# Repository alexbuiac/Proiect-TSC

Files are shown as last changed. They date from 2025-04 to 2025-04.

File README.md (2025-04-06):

# Proiect TSC 2025

## 1. Diagrama bloc a device-ului

```mermaid
flowchart TB
  USB-C -->|5V| Charger["Charger MCP73831"]
  Charger -->LiPo["Battery"]
  LiPo --> LDO["3V3 LDO"]
  
  ESP32["ESP32-C6-WROOM-1"]
  
  LDO -->|3.3V| ESP32
  LDO -->|3.3V| Display
  LDO -->|3.3V| SDCard
  LDO -->|3.3V| RTC
  LDO -->|3.3V| BME688
  LDO -->|3.3V| BatteryGauge
  
  ESP32 -- SPI --> Display["7.5 E-Ink Display Waveshare WSH-13187"]
  ESP32 -- SPI --> SDCard["SD Card Connector"]
  ESP32 -- GPIO --> Buttons["Buttons (3x)"]
  ESP32 -- I2C --> BME688["Environment Sensor BME688"]
  ESP32 -- I2C --> BatteryGauge["Battery Percentage Gauge MAX17048"]
  ESP32 -- I2C --> RTC["Clock DS3231"]
  ESP32 -- USB --> USB-C
  
  LDO -->|3.3V| ESP32
  LDO -->|3.3V| Display
  LDO -->|3.3V| SDCard
  LDO -->|3.3V| RTC
  LDO -->|3.3V| BME688
  LDO -->|3.3V| BatteryGauge
```
## 2. BIll of Materials

| Name of component | Device | Check Prices | DataSheet |
|---|---|---|---|
| BOOT_BUTTON | BUTTON_CUSYOMV1 | https://industry.panasonic.com/global/en/products/control/switch/light-touch/number/evqpuj02k | https://industry.panasonic.com/global/en/products/control/switch/light-touch/number/evqpuj02k |
| C1 | ESP32_WROVER_EAGLE-LTSPICE_CC0402 | https://industry.panasonic.com/global/en/products/control/switch/light-touch/number/evqpuj02k | https://industry.panasonic.com/global/en/products/control/switch/light-touch/number/evqpuj02k |
| C1_BAT | ESP32_WROVER_EAGLE-LTSPICE_CC0402 | #N/A | #N/A |
| C1_BAT1 | EAGLE-LTSPICE_CC0402 | #N/A | #N/A |
| C1_BAT2 | EAGLE-LTSPICE_CC0402 | #N/A | #N/A |
| C2 | ESP32_WROVER_EAGLE-LTSPICE_CC0402 | #N/A | #N/A |
| C2_BAT\ | ESP32_WROVER_EAGLE-LTSPICE_CC0402 | #N/A | #N/A |
| C3 | RCL_CPOL-EUCT3528 | #N/A | #N/A |
| C4 | ESP32_WROVER_EAGLE-LTSPICE_CC0402 | #N/A | #N/A |
| C4_USB | ESP32_WROVER_EAGLE-LTSPICE_CC0402 | #N/A | #N/A |
| C5 | ESP32_WROVER_EAGLE-LTSPICE_CC0402 | #N/A | #N/A |
| C5_USB | ESP32_WROVER_EAGLE-LTSPICE_CC0402 | #N/A | #N/A |
| C6 | ESP32_WROVER_EAGLE-LTSPICE_CC0402 | #N/A | #N/A |
| C7 | ESP32_WROVER_EAGLE-LTSPICE_CC0402 | #N/A | #N/A |
| C8 | ESP32_WROVER_EAGLE-LTSPICE_CC0402 | #N/A | #N/A |
| C9 | EAGLE-LTSPICE_CC0402 | #N/A | #N/A |
| C10 | ESP32_WROVER_EAGLE-LTSPICE_CC0402 | #N/A | #N/A |
| C10_SUPERCAP | CPH3225A | https://www.snapeda.com/parts/CPH3225A/Seiko+Instruments/view-part/?ref=eda | https://www.snapeda.com/parts/CPH3225A/Seiko+Instruments/view-part/?ref=eda |
| CHANGE_BUTTON | BUTTON_CUSYOMV1 | https://industry.panasonic.com/global/en/products/control/switch-light-touch/number/evqpuj02k | https://industry.panasonic.com/global/en/products/control/switch-light-touch/number/evqpuj02k |
| CHG_LED | ADAFRUIT_LEDCHIP-LED0603 | https://www.snapeda.com/parts/KP-1608SURCK/Kingbright/view-part/?ref=search&t=LED%200603 | https://www.snapeda.com/parts/KP-1608SURCK/Kingbright/view-part/?ref=search&t=LED%200603 |
| C_DELAY | ESP32_WROVER_EAGLE-LTSPICE_CC0402 | #N/A | #N/A |
| D1 | USBLC6-2SC6Y | https://www.snapeda.com/parts/USBLC6-2SC6Y/STMicroelectronics/view-part/?ref=eda | https://www.snapeda.com/parts/USBLC6-2SC6Y/STMicroelectronics/view-part/?ref=eda |
| D2 | ESP32_WROVER_AVX---SD0805S020S1R0_AVX_... | https://eu.mouser.com/ProductDetail/KYOCERA-AVX/SD0805S020S1R0?qs=jCA%252BPfw4LHbpkAoSnwrdjw%3D%3D | http://datasheets.avx.com/schottky.pdf |
| D3 | MBR0530 | https://eu.mouser.com/ProductDetail/KYOCERA-AVX/SD0805S020S1R0?qs=jCA%252BPfw4LHbpkAoSnwrdjw%3D%3D | https://eu.mouser.com/ProductDetail/KYOCERA-AVX/SD0805S020S1R0?qs=jCA%252BPfw4LHbpkAoSnwrdjw%3D%3D |
| D4 | MBR0530 | https://www.snapeda.com/parts/MBR0530/Onsemi/view-part/?ref=eda | https://www.snapeda.com/parts/MBR0530/Onsemi/view-part/?ref=eda |
| D5 | MBR0530 | https://www.snapeda.com/parts/MBR0530/Onsemi/view-part/?ref=eda | https://www.snapeda.com/parts/MBR0530/Onsemi/view-part/?ref=eda |
| D6 | PGB1010603MR | https://www.snapeda.com/parts/PGB1010603MR/Littelfuse/view-part/?ref=eda | https://www.snapeda.com/parts/PGB1010603MR/Littelfuse/view-part/?ref=eda |
| D7 | ESP32_WROVER_AVX---SD0805S020S1R0_AVX_... | https://eu.mouser.com/ProductDetail/KYOCERA-AVX/SD0805S020S1R0?qs=jCA%252BPfw4LHbpkAoSnwrdjw%3D%3D | http://datasheets.avx.com/schottky.pdf |
| D8 | PGB1010603MR | https://www.snapeda.com/parts/PGB1010603MR/Littelfuse/view-part/?ref=eda | https://www.snapeda.com/parts/PGB1010603MR/Littelfuse/view-part/?ref=eda |
| D9 | PGB1010603MR | https://www.snapeda.com/parts/PGB1010603MR/Littelfuse/view-part/?ref=eda | https://www.snapeda.com/parts/PGB1010603MR/Littelfuse/view-part/?ref=eda |
| D10 | PGB1010603MR | https://www.snapeda.com/parts/PGB1010603MR/Littelfuse/view-part/?ref=eda | https://www.snapeda.com/parts/PGB1010603MR/Littelfuse/view-part/?ref=eda |
| D11 | PGB1010603MR | https://www.snapeda.com/parts/PGB1010603MR/Littelfuse/view-part/?ref=eda | https://www.snapeda.com/parts/PGB1010603MR/Littelfuse/view-part/?ref=eda |
| D12 | PGB1010603MR | https://www.snapeda.com/parts/PGB1010603MR/Littelfuse/view-part/?ref=eda | https://www.snapeda.com/parts/PGB1010603MR/Littelfuse/view-part/?ref=eda |
| EPD_C1 | ESP32_WROVER_EAGLE-LTSPICE_CC0402 | #N/A | #N/A |
| EPD_C2 | ESP32_WROVER_EAGLE-LTSPICE_CC0402 | #N/A | #N/A |
| EPD_C5 | ESP32_WROVER_EAGLE-LTSPICE_CC0402 | #N/A | #N/A |
| EPD_C6 | ESP32_WROVER_EAGLE-LTSPICE_CC0402 | #N/A | #N/A |
| EPD_C7 | ESP32_WROVER_EAGLE-LTSPICE_CC0402 | #N/A | #N/A |
| EPD_C8 | ESP32_WROVER_EAGLE-LTSPICE_CC0402 | #N/A | #N/A |
| EPD_C9 | ESP32_WROVER_EAGLE-LTSPICE_CC0402 | #N/A | #N/A |
| EPD_C10 | ESP32_WROVER_EAGLE-LTSPICE_CC0402 | #N/A | #N/A |
| EPD_C11 | ESP32_WROVER_EAGLE-LTSPICE_CC0402 | #N/A | #N/A |
| EPD_C12 | ESP32_WROVER_EAGLE-LTSPICE_CC0402 | #N/A | #N/A |
| IC1 | BD5229G-TR | https://componentsearchengine.com/part-view/BD5229G-TR/ROHM%20Semiconductor | https://componentsearchengine.com/part-view/BD5229G-TR/ROHM%20Semiconductor |
| IC4 | XC6220A331MR-G | https://componentsearchengine.com/part-view/XC6220A331MR-G/Torex | https://componentsearchengine.com/part-view/XC6220A331MR-G/Torex |
| J1 | FH34SRJ-24S-0.5SH_99_ | https://componentsearchengine.com/part-view/XC6220A331MR-G/Torex | https://componentsearchengine.com/part-view/XC6220A331MR-G/Torex |
| J2 | SAMACSYS_PARTS_USB4110-GF-A | https://componentsearchengine.com/part-view/USB4110-GF-A/GCT%20(GLOBAL%20CONNECTOR%20TECHNOLOGY | https://componentsearchengine.com/part-view/USB4110-GF-A/GCT%20(GLOBAL%20CONNECTOR%20TECHNOLOGY |
| J3 | QWIIC_CONNECTORJS-1MM | #N/A | #N/A |
| J4 | 112A-TAAR-R03_ATTEND | https://store.comet.srl.ro/Catalogue/Product/43497/ | https://store.comet.srl.ro/Catalogue/Product/43497/ |
| L1 | 744043680IND_4828-WE-TPC_WRE | https://eu.mouser.com/ProductDetail/Wurth-Elektronik/744043680?qs=PGXP4M47uW6VkZq%252BkzjrHA%3D%3D | https://eu.mouser.com/ProductDetail/Wurth-Elektronik/744043680?qs=PGXP4M47uW6VkZq%252BkzjrHA%3D%3D |
| PFMF.050.1 | ESP32C6_VARISTORCN1812 | https://www.mouser.co.uk/ProductDetail/EPCOS-TDK/B72520T0350K062?qs=dEfas%2FXlABIszF52uu7vrg%3D%3D | https://www.mouser.co.uk/ProductDetail/EPCOS-TDK/B72520T0350K062?qs=dEfas%2FXlABIszF52uu7vrg%3D%3D |
| Q1 | ESP32_WROVER_SPARKFUN-DISCRETESEMI_MOSFET_...| https://componentsearchengine.com/part-view/DMG2305UX-7/Diodes%20Incorporated | https://componentsearchengine.com/part-view/DMG2305UX-7/Diodes%20Incorporated |
| Q2 | ESP32_WROVER_SPARKFUN-DISCRETESEMI_MOSFET_...| #N/A | #N/A |
| Q3 | D8 | https://componentsearchengine.com/part-view/SI1308EDL-T1-GE3/Vishay | https://componentsearchengine.com/part-view/SI1308EDL-T1-GE3/Vishay |
| R1 | ESP32_WROVER_EAGLE-LTSPICE_RR0402 | #N/A | #N/A |
| R1-PINH | ESP32_WROVER_EAGLE-LTSPICE_RR0402 | #N/A | #N/A |
| R1-PINH1 | ESP32_WROVER_EAGLE-LTSPICE_RR0402 | #N/A | #N/A |
| R1_BAT | ESP32_WROVER_EAGLE-LTSPICE_RR0402 | #N/A | #N/A |
| R1_PWRUSB | ESP32_WROVER_EAGLE-LTSPICE_RR0402 | #N/A | #N/A |
| R2 | ESP32_WROVER_EAGLE-LTSPICE_RR0402 | https://componentsearchengine.com/part-view/R0402%201%25%20100%20K%20(RC0402FR-07100KL | https://componentsearchengine.com/part-view/R0402%201%25%20100%20K%20(RC0402FR-07100KL |
| R2-PINH | ESP32_WROVER_EAGLE-LTSPICE_RR0402 | #N/A | #N/A |
| R2-PINH1 | ESP32_WROVER_EAGLE-LTSPICE_RR0402 | #N/A | #N/A |
| R2-USB | ESP32_WROVER_EAGLE-LTSPICE_RR0402 | #N/A | #N/A |
| R2-USB1 | ESP32_WROVER_EAGLE-LTSPICE_RR0402 | #N/A | #N/A |
| R2_BAT | ESP32_WROVER_EAGLE-LTSPICE_RR0402 | #N/A | #N/A |
| R3 | ESP32_WROVER_EAGLE-LTSPICE_RR0402 | #N/A | #N/A |
| R4 | ESP32_WROVER_EAGLE-LTSPICE_RR0402 | #N/A | #N/A |
| R5 | ESP32_WROVER_EAGLE-LTSPICE_RR0402 | #N/A | #N/A |
| R6 | ESP32_WROVER_EAGLE-LTSPICE_RR0402 | #N/A | #N/A |
| R7 | ESP32_WROVER_EAGLE-LTSPICE_RR0402 | #N/A | #N/A |
| R8 | ESP32_WROVER_EAGLE-LTSPICE_RR0402 | #N/A | #N/A |
| R9 | ESP32_WROVER_EAGLE-LTSPICE_RR0402 | #N/A | #N/A |
| R10 | ESP32_WROVER_EAGLE-LTSPICE_RR0402 | #N/A | #N/A |
| RESET_BUTTON | BUTTON_CUSYOMV1 | https://industry.panasonic.com/global/en/products/control/switch/light-touch/number/evqpuj02k | https://industry.panasonic.com/global/en/products/control/switch/light-touch/number/evqpuj02k |
| R_BOOT | ESP32_WROVER_EAGLE-LTSPICE_RR0402 | #N/A | #N/A |
| R_CAPACITOR | ESP32_WROVER_EAGLE-LTSPICE_RR0402 | #N/A | #N/A |
| R_CHANGE | ESP32_WROVER_EAGLE-LTSPICE_RR0402 | #N/A | #N/A |
| R_CL1 | ESP32_WROVER_EAGLE-LTSPICE_RR0402 | #N/A | #N/A |
| R_RESET | ESP32_WROVER_EAGLE-LTSPICE_RR0402 | #N/A | #N/A |
| SENSOR2 | ESP32_WROVER_BME680_BME680 | https://www.snapeda.com/parts/BME680/Bosch/view-part/?welcome=home | https://www.snapeda.com/parts/BME680/Bosch/view-part/?welcome=home |
| SJ1 | SJ | https://grabcad.com/library/solder-jumpers-1 | https://grabcad.com/library/solder-jumpers-1 |
| TP1 | TPTP20R | #N/A | #N/A |
| TP2 | TPTP20R | #N/A | #N/A |
| TP3 | TPTP20R | #N/A | #N/A |
| TP4 | TPTP20R | #N/A | #N/A |
| TP5 | TPTP20R | #N/A | #N/A |
| TP6 | TPTP20R | #N/A | #N/A |
| TP7 | TPTP20R | #N/A | #N/A |
| TP8 | TPTP20R | #N/A | #N/A |
| TP9 | TPTP20R | #N/A | #N/A |
| TP10 | TPTP20R | #N/A | #N/A |
| TP11 | TPTP20R | #N/A | #N/A |
| TP12 | TPTP20R | #N/A | #N/A |
| TP13 | TPTP20R | #N/A | #N/A |
| TP14 | TPTP20R | #N/A | #N/A |
| TP15 | TPTP20R | #N/A | #N/A |
| TP16 | TPTP20R | #N/A | #N/A |
| TP17 | TPTP20R | #N/A | #N/A |
| U1 | W25Q512JVEIQ | https://www.snapeda.com/parts/W25Q512JVEIQ/Winbond+Electronics/view-part/?ref=eda | https://www.snapeda.com/parts/W25Q512JVEIQ/Winbond+Electronics/view-part/?ref=eda |
| U2 | ESP32-C6-WROOM-1-N8 | https://www.snapeda.com/parts/ESP32-C6-WROOM-1-N8/Espressif+Systems/view-part/?ref=eda | https://www.snapeda.com/parts/ESP32-C6-WROOM-1-N8/Espressif+Systems/view-part/?ref=eda |
| U3 | DS3231SN# | https://www.snapeda.com/parts/DS3231SN%23/Analog+Devices/view-part/?ref=eda | https://www.snapeda.com/parts/DS3231SN%23/Analog+Devices/view-part/?ref=eda |
| U4 | MAX17048G+T10 | https://www.snapeda.com/parts/MAX17048G+T10/Analog+Devices/view-part/?ref=eda | https://www.snapeda.com/parts/MAX17048G+T10/Analog+Devices/view-part/?ref=eda |
| U5 | ESP32_WROVER_SPARKFUN-IC-POWER_MCP73831 | https://eu.mouser.com/ProductDetail/Microchip-Technology/MCP73831T-2ACI-OT?qs=yUQqVecv4qvbBQBGbHx0Mw%3D%3Dcf | https://eu.mouser.com/ProductDetail/Microchip-Technology/MCP73831T-2ACI-OT?qs=yUQqVecv4qvbBQBGbHx0Mw%3D%3Dcf |

## 3. Descrierea in detaliu a functionalitatilor hardware 

### 1. Microcontroller – ESP32-C6

- **Procesor**: 32-bit RISC-V, cu frecvență de până la 160MHz.
    
- **Memorie**: 512KB SRAM intern și 8MB flash extern (W25Q512JVEIQ).
    
- **Conectivitate**: Wi-Fi 6 (802.11ax), Bluetooth 5 (LE), USB 2.0 (full-speed).
    
- **Periferice**: SPI, I²C, UART, GPIO multiple.
    
- **Consum**: Posibilitate de moduri low-power (sleep, deep sleep).

### 2. Senzor de Mediu – BME688

- **Parametri măsurați**: Temperatură, Umiditate, Presiune și Calitate aer (VOC/eCO2).
    
- **Interfață**: I²C la 400kHz (SDA și SCL).
    
- **Consum**: Foarte mic (în jur de 2.1µA în standby și până la câteva mA în mod de măsurare).

### 3. Afișajul E-Paper (7.5 inch)

- **Model**: Waveshare (sau echivalent) cu rezoluție 800×480.
    
- **Interfață**: 4-wire SPI + semnale de control (CS, DC, RST, BUSY).
    
- **Consum**: Foarte redus în mod static (după refresh), dar necesită un curent mai mare în timpul refresh-ului (aprox. 15–25mA, în funcție de modul de actualizare).

### 4. Baterie și Managementul Energiei

- **Baterie Li-Po 2500mAh** (3.7V nominal).
    
- **IC de Încărcare**: MCP73831 (Microchip) – încărcare Li-Po prin USB-C (până la 1A).
    
- **Fuel Gauge**: MAX17048 – monitorizează nivelul de încărcare, tensiunea și starea bateriei (I²C).
    
- **LDO**: XC6220A331MR-G (exemplu) sau echivalent, pentru a asigura 3.3V stabil pentru microcontroller și restul componentelor.

### 5. USB-C Port

- **Rol**: Încărcare baterie + Transfer de date (USB 2.0 full-speed).
    
- **Protecții**: ESD (USBLC6-2SC6Y) + rezistențe de terminare.
    
- **Posibilitate**: Actualizări firmware prin USB (bootloader + tool extern) sau direct OTA prin Wi-Fi.

### 6. Butoane (3x Tactile Switch)

- **Tip**: Tactile switch Panasonic (sau echivalent).
    
- **Funcții**: Navigare meniu, selectare opțiune, întoarcere pagină etc.
    
- **Conexiune**: Fiecare buton se leagă la un GPIO al ESP32-C6 printr-un circuit de debouncing (rezistență și condensator) sau se poate face debouncing în firmware.

### 7. Conector Qwiic (I²C)

- Conector standard cu 4 pini: VCC, GND, SDA, SCL.
    
- Permite atașarea rapidă a altor senzori sau module I²C (expansiune, testare, prototipare rapidă).

### 8. SD Memory Card Connector (112A-TAAR-R03)

- **Rol**: Posibilitate de stocare externă pentru e-book-uri, log-uri sau update-uri firmware.
    
- **Interfață**: Poate fi SD (1-bit / 4-bit) sau SPI, în funcție de configurația firmware-ului.

### 10. Memorii Suplimentare

- **W25Q512JVEIQ** (Flash extern) – conectat la ESP32-C6 prin SPI dedicat (quad SPI).
    
    - Aici se stochează firmware-ul și datele mari (e-book-uri etc.).

### 9. RTC – DS3231

- **Funcție**: Asigură un ceas de timp real foarte precis.
    
- **Interfață**: I²C (aceeași magistrală cu BME688 și MAX17048).
    
- **Backup**: Supercondensator sau baterie secundară pentru a menține timpul și în absența alimentării principale.    

## 4. Folosirea pinilor ESP32-C6

| Pin ESP32-C6 | Componentă / Semnal | De ce? |
| --- | --- | --- |
| **GPIO1 (SDA)** | I²C SDA (BME688, MAX17048, DS3231, Qwiic) | Partajare magistrală I²C pentru toți senzorii și RTC. |
| **GPIO2 (SCL)** | I²C SCL (BME688, MAX17048, DS3231, Qwiic) | Linia de clock pentru I²C. |
| **GPIO5** | SPI MISO (E-Paper) | Citirea datelor/statusului display-ului (dacă e suportat). |
| **GPIO6** | SPI MOSI (E-Paper) | Trimiterea datelor către e-paper. |
| **GPIO7** | SPI CLK (E-Paper) | Semnal de clock pentru e-paper. |
| **GPIO8** | SPI CS (E-Paper) | Chip Select pentru e-paper. |
| **GPIO9** | E-Paper DC (Data/Command) | Semnal care diferențiază datele de comenzile pentru afișaj. |
| **GPIO10** | E-Paper RST | Reset hardware pentru e-paper. |
| **GPIO11** | E-Paper BUSY | Intrare din display, indică dacă este ocupat. |
| **GPIO12** | Button #1 | Intrare digitală pentru buton (ex. NEXT page). |
| **GPIO13** | Button #2 | Intrare digitală pentru buton (ex. PREV page). |
| **GPIO14** | Button #3 | Intrare digitală pentru buton (ex. MENU/OK). |
| **GPIO15** | MAX17048 ALERT (opțional) | Avertizare nivel baterie scăzut. |
| **GPIO16** | USB D+ (intern la USB PHY) | Pin dedicat pentru USB 2.0. (În mod normal pin hardware fix). |
| **GPIO17** | USB D- (intern la USB PHY) | Pin dedicat pentru USB 2.0. (La fel, pin fix). |
| **GPIO18** | LED de status (opțional) | Indicator pentru diverse stări (Wi-Fi, încărcare, etc.). |
| **GPIO19** | SD Card CS (opțional) | Chip Select pentru cardul SD (dacă se folosește SPI). |
| **GPIO20** | SD Card MISO (opțional) | Intrare date de la card SD. |
| **GPIO21** | SD Card MOSI (opțional) | Ieșire date către card SD. |
| **GPIO4** | SD Card CLK (opțional) | Semnal de clock pentru card SD (SPI). |

## 5. Imagini
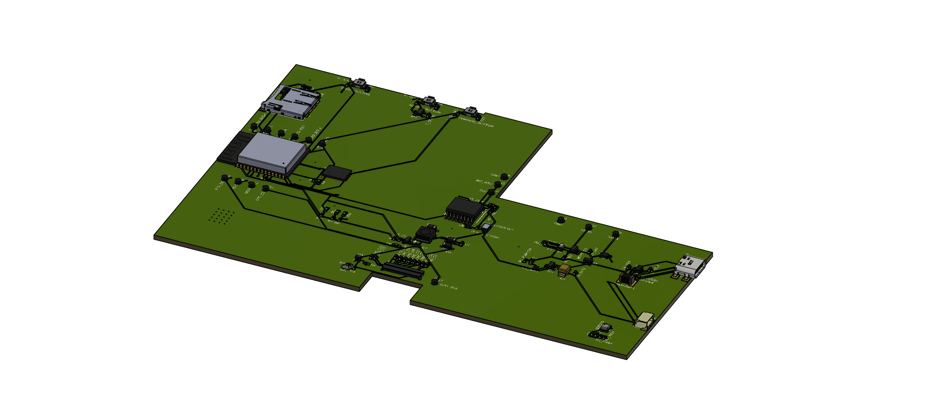
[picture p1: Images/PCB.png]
PCB

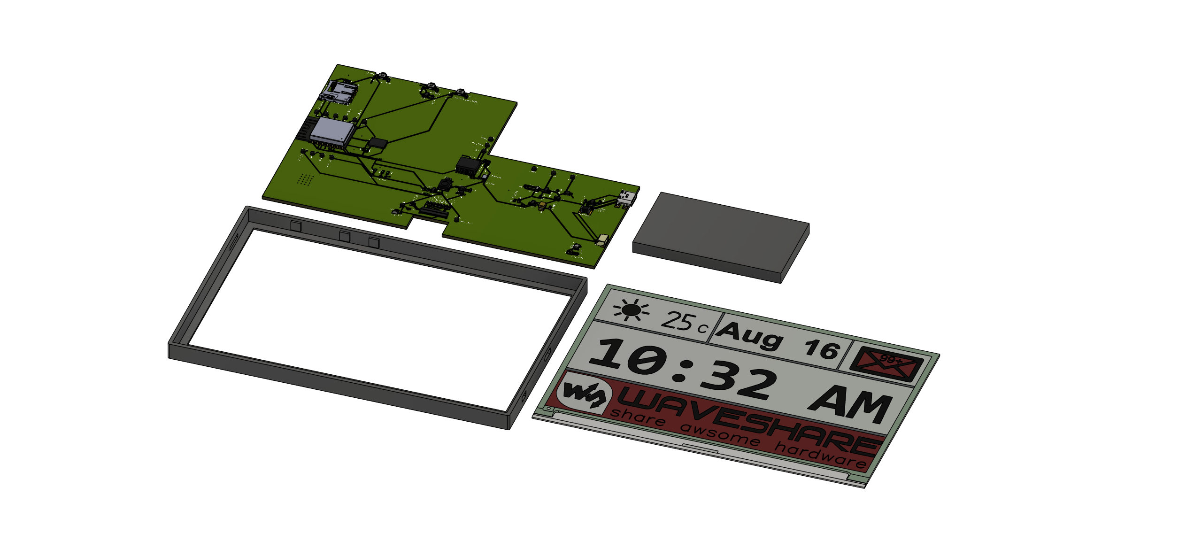
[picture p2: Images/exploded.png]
exploded


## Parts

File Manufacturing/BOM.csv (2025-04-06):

Qty | Value | Device | Package | Parts | Description | ARROW_PART_NUMBER | ARROW_PRICE-STOCK | AVAILABILITY | CENTROID_NOT_SPECIFIED | CHECK_PRICES | COPYRIGHT | DATASHEET | DESCRIPTION | DIGIKEY_DESCRIPTION | DIGIKEY_PART_NUMBER | HEIGHT | LEAD_FREE | MANUFACTURER_NAME | MANUFACTURER_PART_NUMBER | MF | MFR_NAME | MOUSER_PART_NUMBER | MOUSER_PRICE-STOCK | MOUSER_TESTING_PART_NUMBER | MOUSER_TESTING_PRICE-STOCK | MP | MPN | PACKAGE | POPULARITY | PREFIX | PRICE | PROD_ID | PURCHASE-URL | ROHS | SNAPEDA_LINK | SPICEMODEL | SPICEPREFIX | TEMPERATURE_RANGE_HIGH | TEMPERATURE_RANGE_LOW | TP_SIGNAL_NAME | VALUE
1 |  | ADAFRUIT_LEDCHIP-LED0603 | ADAFRUIT_CHIP-LED0603 | CHG_LED | LED
1 |  | ESP32C6_VARISTORCN1812 | ESP32C6_VARISTOR_CT/CN1812 | PFMF.050.1 | VARISTOR |  |  |  |  |  |  |  |  |  |  |  |  |  |  |  |  |  |  |  |  |  |  |  | 0
1 |  | SAMACSYS_PARTS_USB4110-GF-A | SAMACSYS_PARTS_USB4110GFA | J2 | CONN USB 2.0 TYPE-C R/A SMT |  |  |  |  |  |  |  | CONN USB 2.0 TYPE-C R/A SMT |  |  | 3.26mm |  | GCT (GLOBAL CONNECTOR TECHNOLOGY) | USB4110-GF-A |  |  | 640-USB4110-GF-A | https://www.mouser.co.uk/ProductDetail/GCT/USB4110-GF-A?qs=KUoIvG%2F9IlYiZvIXQjyJeA%3D%3D
1 |  | SJ | SJ | SJ1 | SMD solder JUMPER |  |  |  |  |  |  |  |  |  |  |  |  |  |  |  |  |  |  |  |  |  |  |  | 3
1 | 0.47 | ESP32_WROVER_EAGLE-LTSPICE_RR0402 | ESP32_WROVER_EAGLE-LTSPICE_R0402 | R3 | RESISTOR, European symbol |  |  |  |  |  |  |  |  |  |  |  |  |  |  |  |  |  |  |  |  |  |  |  |  |  |  |  |  |  |  | NONE | R
1 | 100k | ESP32_WROVER_EAGLE-LTSPICE_RR0402 | ESP32_WROVER_EAGLE-LTSPICE_R0402 | R1_PWRUSB | RESISTOR, European symbol |  |  |  |  |  |  |  |  |  |  |  |  |  |  |  |  |  |  |  |  |  |  |  |  |  |  |  |  |  |  | NONE | R
8 | 100nF | ESP32_WROVER_EAGLE-LTSPICE_CC0402 | ESP32_WROVER_EAGLE-LTSPICE_C0402 | C1, C2, C4_USB, C6, C8, C9, C10, C_DELAY | CAPACITOR, European symbol |  |  |  |  |  |  |  |  |  |  |  |  |  |  |  |  |  |  |  |  |  |  |  |  |  |  |  |  |  |  | NONE | C
1 | 100uF TANT | RCL_CPOL-EUCT3528 | RCL_CT3528 | C3 | POLARIZED CAPACITOR, European symbol |  |  |  |  |  |  |  |  |  |  |  |  |  |  |  |  |  |  |  |  |  |  |  | 0 |  |  |  |  |  |  |  | C
14 | 10K | ESP32_WROVER_EAGLE-LTSPICE_RR0402 | ESP32_WROVER_EAGLE-LTSPICE_R0402 | R1_PINH, R1_PINH1, R2_PINH, R2_PINH1, R5, R6, R7, R8, R9, R10, R_BOOT, R_CHANGE, R_CL1, R_RESET | RESISTOR, European symbol |  |  |  |  |  |  |  |  |  |  |  |  |  |  |  |  |  |  |  |  |  |  |  |  |  |  |  |  |  |  | NONE | R
2 | 10k | ESP32_WROVER_EAGLE-LTSPICE_RR0402 | ESP32_WROVER_EAGLE-LTSPICE_R0402 | R1, R4 | RESISTOR, European symbol |  |  |  |  |  |  |  |  |  |  |  |  |  |  |  |  |  |  |  |  |  |  |  |  |  |  |  |  |  |  | NONE | R
1 | 10uF | ESP32_WROVER_EAGLE-LTSPICE_CC0402 | ESP32_WROVER_EAGLE-LTSPICE_C0402 | C7 | CAPACITOR, European symbol |  |  |  |  |  |  |  |  |  |  |  |  |  |  |  |  |  |  |  |  |  |  |  |  |  |  |  |  |  |  | NONE | C
1 | 112A-TAAR-R03_ATTEND | 112A-TAAR-R03_ATTEND | 112ATAARR03ATTEND | J4 | Micro SD Card Socket, Push-Push Type, Top Mount, SMT, H=1.83mm, 10u |  |  |  |  |  |  |  | Micro SD Card Socket | Push-Push Type | Top Mount | SMT | H=1.83mm | 10u |  |  | 1.9mm |  | ATTEND | 112A-TAAR-R03 ATTEND
1 | 15 | ESP32_WROVER_EAGLE-LTSPICE_RR0402 | ESP32_WROVER_EAGLE-LTSPICE_R0402 | R_CAPACITOR | RESISTOR, European symbol |  |  |  |  |  |  |  |  |  |  |  |  |  |  |  |  |  |  |  |  |  |  |  |  |  |  |  |  |  |  | NONE | R
1 | 1uF | ESP32_WROVER_EAGLE-LTSPICE_CC0402 | ESP32_WROVER_EAGLE-LTSPICE_C0402 | C5 | CAPACITOR, European symbol |  |  |  |  |  |  |  |  |  |  |  |  |  |  |  |  |  |  |  |  |  |  |  |  |  |  |  |  |  |  | NONE | C
10 | 1uF/50V | ESP32_WROVER_EAGLE-LTSPICE_CC0402 | ESP32_WROVER_EAGLE-LTSPICE_C0402 | EPD_C1, EPD_C2, EPD_C5, EPD_C6, EPD_C7, EPD_C8, EPD_C9, EPD_C10, EPD_C11, EPD_C12 | CAPACITOR, European symbol |  |  |  |  |  |  |  |  |  |  |  |  |  |  |  |  |  |  |  |  |  |  |  |  |  |  |  |  |  |  | NONE | C
1 | 2.2 | ESP32_WROVER_EAGLE-LTSPICE_RR0402 | ESP32_WROVER_EAGLE-LTSPICE_R0402 | R2 | RESISTOR, European symbol |  |  |  |  |  |  |  |  |  |  |  |  |  |  |  |  |  |  |  |  |  |  |  |  |  |  |  |  |  |  | NONE | R
1 | 200 | ESP32_WROVER_EAGLE-LTSPICE_RR0402 | ESP32_WROVER_EAGLE-LTSPICE_R0402 | R1_BAT | RESISTOR, European symbol |  |  |  |  |  |  |  |  |  |  |  |  |  |  |  |  |  |  |  |  |  |  |  |  |  |  |  |  |  |  | NONE | R
2 | 20V/4.2A/52mO/1.4W | ESP32_WROVER_SPARKFUN-DISCRETESEMI_MOSFET_PCH-DMG2305UX-7 | ESP32_WROVER_SPARKFUN-DISCRETESEMI_SOT23-3 | Q1, Q2 | P-channel MOSFETs |  |  |  |  |  |  |  |  |  |  |  |  |  |  |  |  |  |  |  |  |  |  |  |  |  |  | TRAN-14388 |  |  |  |  |  |  |  |  | 20V/4.2A/52mO/1.4W
1 | 2k | ESP32_WROVER_EAGLE-LTSPICE_RR0402 | ESP32_WROVER_EAGLE-LTSPICE_R0402 | R2_BAT | RESISTOR, European symbol |  |  |  |  |  |  |  |  |  |  |  |  |  |  |  |  |  |  |  |  |  |  |  |  |  |  |  |  |  |  | NONE | R
5 | 4.7uF | ESP32_WROVER_EAGLE-LTSPICE_CC0402 | ESP32_WROVER_EAGLE-LTSPICE_C0402 | C1_BAT, C1_BAT1, C1_BAT2, C2_BAT, C5_USB | CAPACITOR, European symbol |  |  |  |  |  |  |  |  |  |  |  |  |  |  |  |  |  |  |  |  |  |  |  |  |  |  |  |  |  |  | NONE | C
1 | 4.7uF/25V | ESP32_WROVER_EAGLE-LTSPICE_CC0402 | ESP32_WROVER_EAGLE-LTSPICE_C0402 | C4 | CAPACITOR, European symbol |  |  |  |  |  |  |  |  |  |  |  |  |  |  |  |  |  |  |  |  |  |  |  |  |  |  |  |  |  |  | NONE | C
2 | 5k1 | ESP32_WROVER_EAGLE-LTSPICE_RR0402 | ESP32_WROVER_EAGLE-LTSPICE_R0402 | R2-USB, R2-USB1 | RESISTOR, European symbol |  |  |  |  |  |  |  |  |  |  |  |  |  |  |  |  |  |  |  |  |  |  |  |  |  |  |  |  |  |  | NONE | R
1 | 744043680IND_4828-WE-TPC_WRE | 744043680IND_4828-WE-TPC_WRE | IND_4828-WE-TPC_WRE | L1 |  |  |  |  |  |  | Copyright (C) 2024 Ultra Librarian. All rights reserved. |  |  |  |  |  |  |  | 744043680 |  | Wurth Electronics
1 | BD5229G-TR | BD5229G-TR | SOT95P280X120-5N | IC1 | Voltage Detector with Adjustable Delay Time: CMOS processes are utilized to develop high precision, low current consumption CMOS reset ICs that allow arbitrary setting of the delay time. The extensive lineup includes both Nch Open Drain and CMOS output types in a wide range of detection voltages (from 2.3V to 6.0V, in 0.1V steps), enabling selection of the ideal solution based on customer requirements. In addition, the entire series is of course both lead-free and RoHS-compliant. |  |  |  |  |  |  |  | Voltage Detector with Adjustable Delay Time: CMOS processes are utilized to develop high precision | low current consumption CMOS reset ICs that allow arbitrary setting of the delay time. The extensive lineup includes both Nch Open Drain and CMOS output types in a wide range of detection voltages (from 2.3V to 6.0V | in 0.1V steps) | enabling selection of the ideal solution based on customer requirements. In addition | the entire series is of course both lead-free and RoHS-compliant. |  |  | 1.25mm |  | ROHM Semiconductor | BD5229G-TR |  |  | 755-BD5229G-TR | https://www.mouser.co.uk/ProductDetail/ROHM-Semiconductor/BD5229G-TR?qs=4kLU8WoGk0vvnhrrYwdszw%3D%3D
1 | BME688 | ESP32_WROVER_BME680_BME680 | ESP32_WROVER_BME680_PSON80P300X300X100-8N | SENSOR2 | Integrated Environmental Unit |  |  | Unavailable |  |  |  |  | Integrated Environmental Unit |  |  |  |  |  |  | Bosch Sensortec |  |  |  |  |  | BME680 |  | LGA-8 Bosch Tools |  |  | None
3 | BUTTON_CUSYOMV1 | BUTTON_CUSYOMV1 | MYBUTTON | BOOT_BUTTON, CHANGE_BUTTON, RESET_BUTTON
1 | CPH3225A | CPH3225A | CAPCP3225X100N | C10_SUPERCAP | Cap 0.011F 3.3V 1210 Flat Check availability |  |  | Not in stock |  | https://www.snapeda.com/parts/CPH3225A/Seiko+Instruments/view-part/?ref=eda |  |  | 11 mF (EDLC) Supercapacitor 3.3 V 1210 (3225 Metric) - - |  |  |  |  |  |  | Seiko Instruments |  |  |  |  |  | CPH3225A |  | 1210 Seiko |  |  | None |  | https://www.snapeda.com/api/url_track_click_mouser/?unipart_id=562593&manufacturer=Seiko Instruments&part_name=CPH3225A&search_term=None |  | https://www.snapeda.com/parts/CPH3225A/Seiko+Instruments/view-part/?ref=snap
1 | DS3231SN# | DS3231SN# | SOIC127P1032X265-16N | U3 | Real Time Clock Serial 16-Pin SOIC W T/R Check availability |  |  | In Stock |  | https://www.snapeda.com/parts/DS3231SN%23/Analog+Devices/view-part/?ref=eda |  |  | Extremely Accurate I²C-Integrated RTC/TCXO/Crystal |  |  |  |  |  |  | Analog Devices |  |  |  |  |  | DS3231SN# |  | SOIC-16 Maxim |  |  | None |  | https://www.snapeda.com/api/url_track_click_mouser/?unipart_id=99048&manufacturer=Analog Devices&part_name=DS3231SN#&search_term=None |  | https://www.snapeda.com/parts/DS3231SN%23/Analog+Devices/view-part/?ref=snap
1 | ESP32-C6-WROOM-1-N8 | ESP32-C6-WROOM-1-N8 | XCVR_ESP32-C6-WROOM-1-N8 | U2 | Check availability |  |  | In Stock |  | https://www.snapeda.com/parts/ESP32-C6-WROOM-1-N8/Espressif+Systems/view-part/?ref=eda |  |  | Multiprotocol Modules ESP32-C6 module | Wi-Fi 6 in 2.4 GHz band | Bluetooth 5 | Zigbee 3.0 and Thread. ESP34-WROOM Compatible - ENGINEERING SAMPLE |  |  |  |  |  |  | Espressif Systems |  |  |  |  |  | ESP32-C6-WROOM-1-N8 |  | None |  |  | None |  |  |  | https://www.snapeda.com/parts/ESP32-C6-WROOM-1-N8/Espressif+Systems/view-part/?ref=snap
1 | ESP32_WROVER_SPARKFUN-IC-POWER_MCP73831 | ESP32_WROVER_SPARKFUN-IC-POWER_MCP73831 | ESP32_WROVER_SPARKFUN-IC-POWER_SOT23-5 | MCP73831 | MCP73831T Li-Ion, Li-Pol Controller |  |  |  |  |  |  |  |  |  |  |  |  |  |  |  |  |  |  |  |  |  |  |  |  |  |  | IC-09995
1 | FH34SRJ-24S-0.5SH_99_ | FH34SRJ-24S-0.5SH_99_ | FH34SRJ24S05SH99 | J1 | (0.50mm) Surface Mount, Right Angle |  |  |  |  |  |  |  | 24 Position FFC | FPC Connector Contacts | (0.50mm) Surface Mount | Right Angle |  |  | 1.1mm |  | Hirose | FH34SRJ-24S-0.5SH(99) |  |  | 798-FH34SRJ24S05SH99 | https://www.mouser.co.uk/ProductDetail/Hirose-Connector/FH34SRJ-24S-0.5SH99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
1 | MAX17048G+T10 | MAX17048G+T10 | SON50P200X200X80-9N | U4 | Check availability |  |  | In Stock |  | https://www.snapeda.com/parts/MAX17048G+T10/Analog+Devices/view-part/?ref=eda |  |  | 3µA 1-Cell/2-Cell Fuel Gauge with ModelGauge |  |  |  |  |  |  | Analog Devices |  |  |  |  |  | MAX17048G+T10 |  | TDFN-8 Maxim |  |  | None |  | https://www.snapeda.com/api/url_track_click_mouser/?unipart_id=329239&manufacturer=Analog Devices&part_name=MAX17048G+T10&search_term=None |  | https://www.snapeda.com/parts/MAX17048G+T10/Analog+Devices/view-part/?ref=snap
3 | MBR0530 | MBR0530 | SOD3716X135N | D3, D4, D5 | ON SEMICONDUCTOR - MBR0530 - DIODE, SCHOTTKY, 0.5A, 30V, SOD-123 |  |  | In Stock |  | https://www.snapeda.com/parts/MBR0530/Onsemi/view-part/?ref=eda |  |  | Diode Schottky 30 V 500mA Surface Mount SOD-123 |  |  |  |  |  |  | ON Semiconductor |  |  |  |  |  | MBR0530 |  | SOD-123-2 ON Semiconductor |  |  | None |  | https://www.snapeda.com/api/url_track_click_mouser/?unipart_id=179458&manufacturer=ON Semiconductor&part_name=MBR0530&search_term=None |  | https://www.snapeda.com/parts/MBR0530/Onsemi/view-part/?ref=snap
6 | PGB1010603MR | PGB1010603MR | DIOC1608X36N | D6, D8, D9, D10, D11, D12 | Check availability |  |  | In Stock |  | https://www.snapeda.com/parts/PGB1010603MR/Littelfuse/view-part/?ref=eda |  |  | 150V (Typ) Clamp - Ipp Tvs Diode Surface Mount 0603 (1608 Metric) |  |  |  |  |  |  | Littelfuse Inc. |  |  |  |  |  | PGB1010603MR |  | 0603 Littelfuse Inc. |  |  | None |  | https://www.snapeda.com/api/url_track_click_mouser/?unipart_id=5659453&manufacturer=Littelfuse Inc.&part_name=PGB1010603MR&search_term=None |  | https://www.snapeda.com/parts/PGB1010603MR/Littelfuse/view-part/?ref=snap
1 | QWIIC_RIGHT_ANGLE | QWIIC_CONNECTORJS-1MM | JST04_1MM_RA | J3 | SparkFun I2C Standard Qwiic Connector |  |  |  |  |  |  |  |  |  |  |  |  |  |  |  |  |  |  |  |  |  |  |  |  |  |  | CONN-13694 |  |  |  |  |  |  |  |  | QWIIC_RIGHT_ANGLE
2 | SD0805S020S1R0 | ESP32_WROVER_AVX---SD0805S020S1R0_AVX_SD0805S020S1R0_0_0AVX_SD0805S020S1R0_0_0 | ESP32_WROVER_AVX---SD0805S020S1R0_AVX_SD0805S020S1R0_0 | D2, D7 | Schottky Barrier Rectifier Diode |  |  |  | No |  |  | http://datasheets.avx.com/schottky.pdf |  | DIODE SCHOTTKY 20V 1A 0805 | 478-7800-1-ND |  | yes |  |  | AVX |  | 581-SD0805S020S1R0 |  |  |  |  |  | 0805 (2012 metric) |  | D |  |  |  | yes |  |  |  | +125°C | -55°C
1 | SI1308EDL-T1-GE3 | SI1308EDL-T1-GE3 | SOT65P210X110-3N | Q3 | MOSFET N-Ch 30V 1.5A TrenchFET SC70 Vishay Si1308EDL-T1-GE3 N-channel MOSFET Transistor, 1.5 A, 30 V, 3-Pin SC-70 |  |  | In Stock |  | https://www.snapeda.com/parts/SI1308EDL-T1-GE3/Vishay+Siliconix/view-part/?ref=eda |  |  | Si1308EDL-T1-GE3 N-channel MOSFET Transistor | 1.5 A | 30 V | 3-Pin SC-70 | Siliconix / Vishay SI1308EDL-T1-GE3 |  |  |  |  |  |  | Vishay Siliconix |  |  |  |  |  | SI1308EDL-T1-GE3 |  | SOT-323 Vishay Semiconductor |  |  | None |  | https://www.snapeda.com/api/url_track_click_mouser/?unipart_id=274603&manufacturer=Vishay Siliconix&part_name=SI1308EDL-T1-GE3&search_term=None |  | https://www.snapeda.com/parts/SI1308EDL-T1-GE3/Vishay+Siliconix/view-part/?ref=snap
17 | TPTP20R | TPTP20R | TP20R | TP1, TP2, TP3, TP4, TP5, TP6, TP7, TP8, TP9, TP10, TP11, TP12, TP13, TP14, TP15, TP16, TP17 | Test pad |  |  |  |  |  |  |  |  |  |  |  |  |  |  |  |  |  |  |  |  |  |  |  | 2
1 | USBLC6-2SC6Y | USBLC6-2SC6Y | SOT95P280X145-6N | D1 | Low Cap. ESD Protection Auto SOT-23-6 STMicroelectronics USBLC6-2SC6Y, Dual Uni-Directional TVS Diode Array, 6-Pin SOT-23 |  |  | In Stock |  | https://www.snapeda.com/parts/USBLC6-2SC6Y/STMicroelectronics/view-part/?ref=eda |  |  | 17V Clamp 5A (8/20µs) Ipp Tvs Diode Surface Mount SOT-23-6 |  |  |  |  |  |  | STMicroelectronics |  |  |  |  |  | USBLC6-2SC6Y |  | SOT-23-6 STMicroelectronics |  |  | None |  |  |  | https://www.snapeda.com/parts/USBLC6-2SC6Y/STMicroelectronics/view-part/?ref=snap
1 | W25Q512JVEIQ | W25Q512JVEIQ | SON127P600X800X80-9N | U1 | Check availability |  |  | In Stock |  | https://www.snapeda.com/parts/W25Q512JVEIQ/Winbond+Electronics/view-part/?ref=eda |  |  | FLASH - NOR Memory IC 512Mb (64M x 8) SPI - Quad I/O 133 MHz 8-WSON (8x6) |  |  |  |  |  |  | Winbond Electronics |  |  |  |  |  | W25Q512JVEIQ |  | Package |  |  | None |  |  |  | https://www.snapeda.com/parts/W25Q512JVEIQ/Winbond+Electronics/view-part/?ref=snap
1 | XC6220A331MR-G | XC6220A331MR-G | SOT95P280X120-5N | IC4 | LDO Voltage Regulators |  |  |  |  |  |  |  | LDO Voltage Regulators |  |  | 1.2mm |  | Torex | XC6220A331MR-G |  |  | 865-XC6220A331MR-G | https://www.mouser.co.uk/ProductDetail/Torex-Semiconductor/XC6220A331MR-G?qs=AsjdqWjXhJ8ZSWznL1J0gg%3D%3D

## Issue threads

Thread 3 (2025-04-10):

Silkscreen

RaresClinci, 2025-04-10:
Exista zone unde textul de pe silkscreen iese de pe placa(langa butoane) si text prea mic care nu e citet pe PCB 3D(in zona cu 3 diode si 3 rezistente)

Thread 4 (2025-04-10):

Label TP-uri

RaresClinci, 2025-04-10:
Pe silkscreen, nu sunt puse la TP-uri labeluri care denumesc pinul pe care il reprezinta:
“Test pad-urile vor fi clar marcate în silkscreen cu numele semnalelor pe care le poartă (de ex. MISO, MOSI, Rx, GND, etc.).”

Closed 2025-04-15.

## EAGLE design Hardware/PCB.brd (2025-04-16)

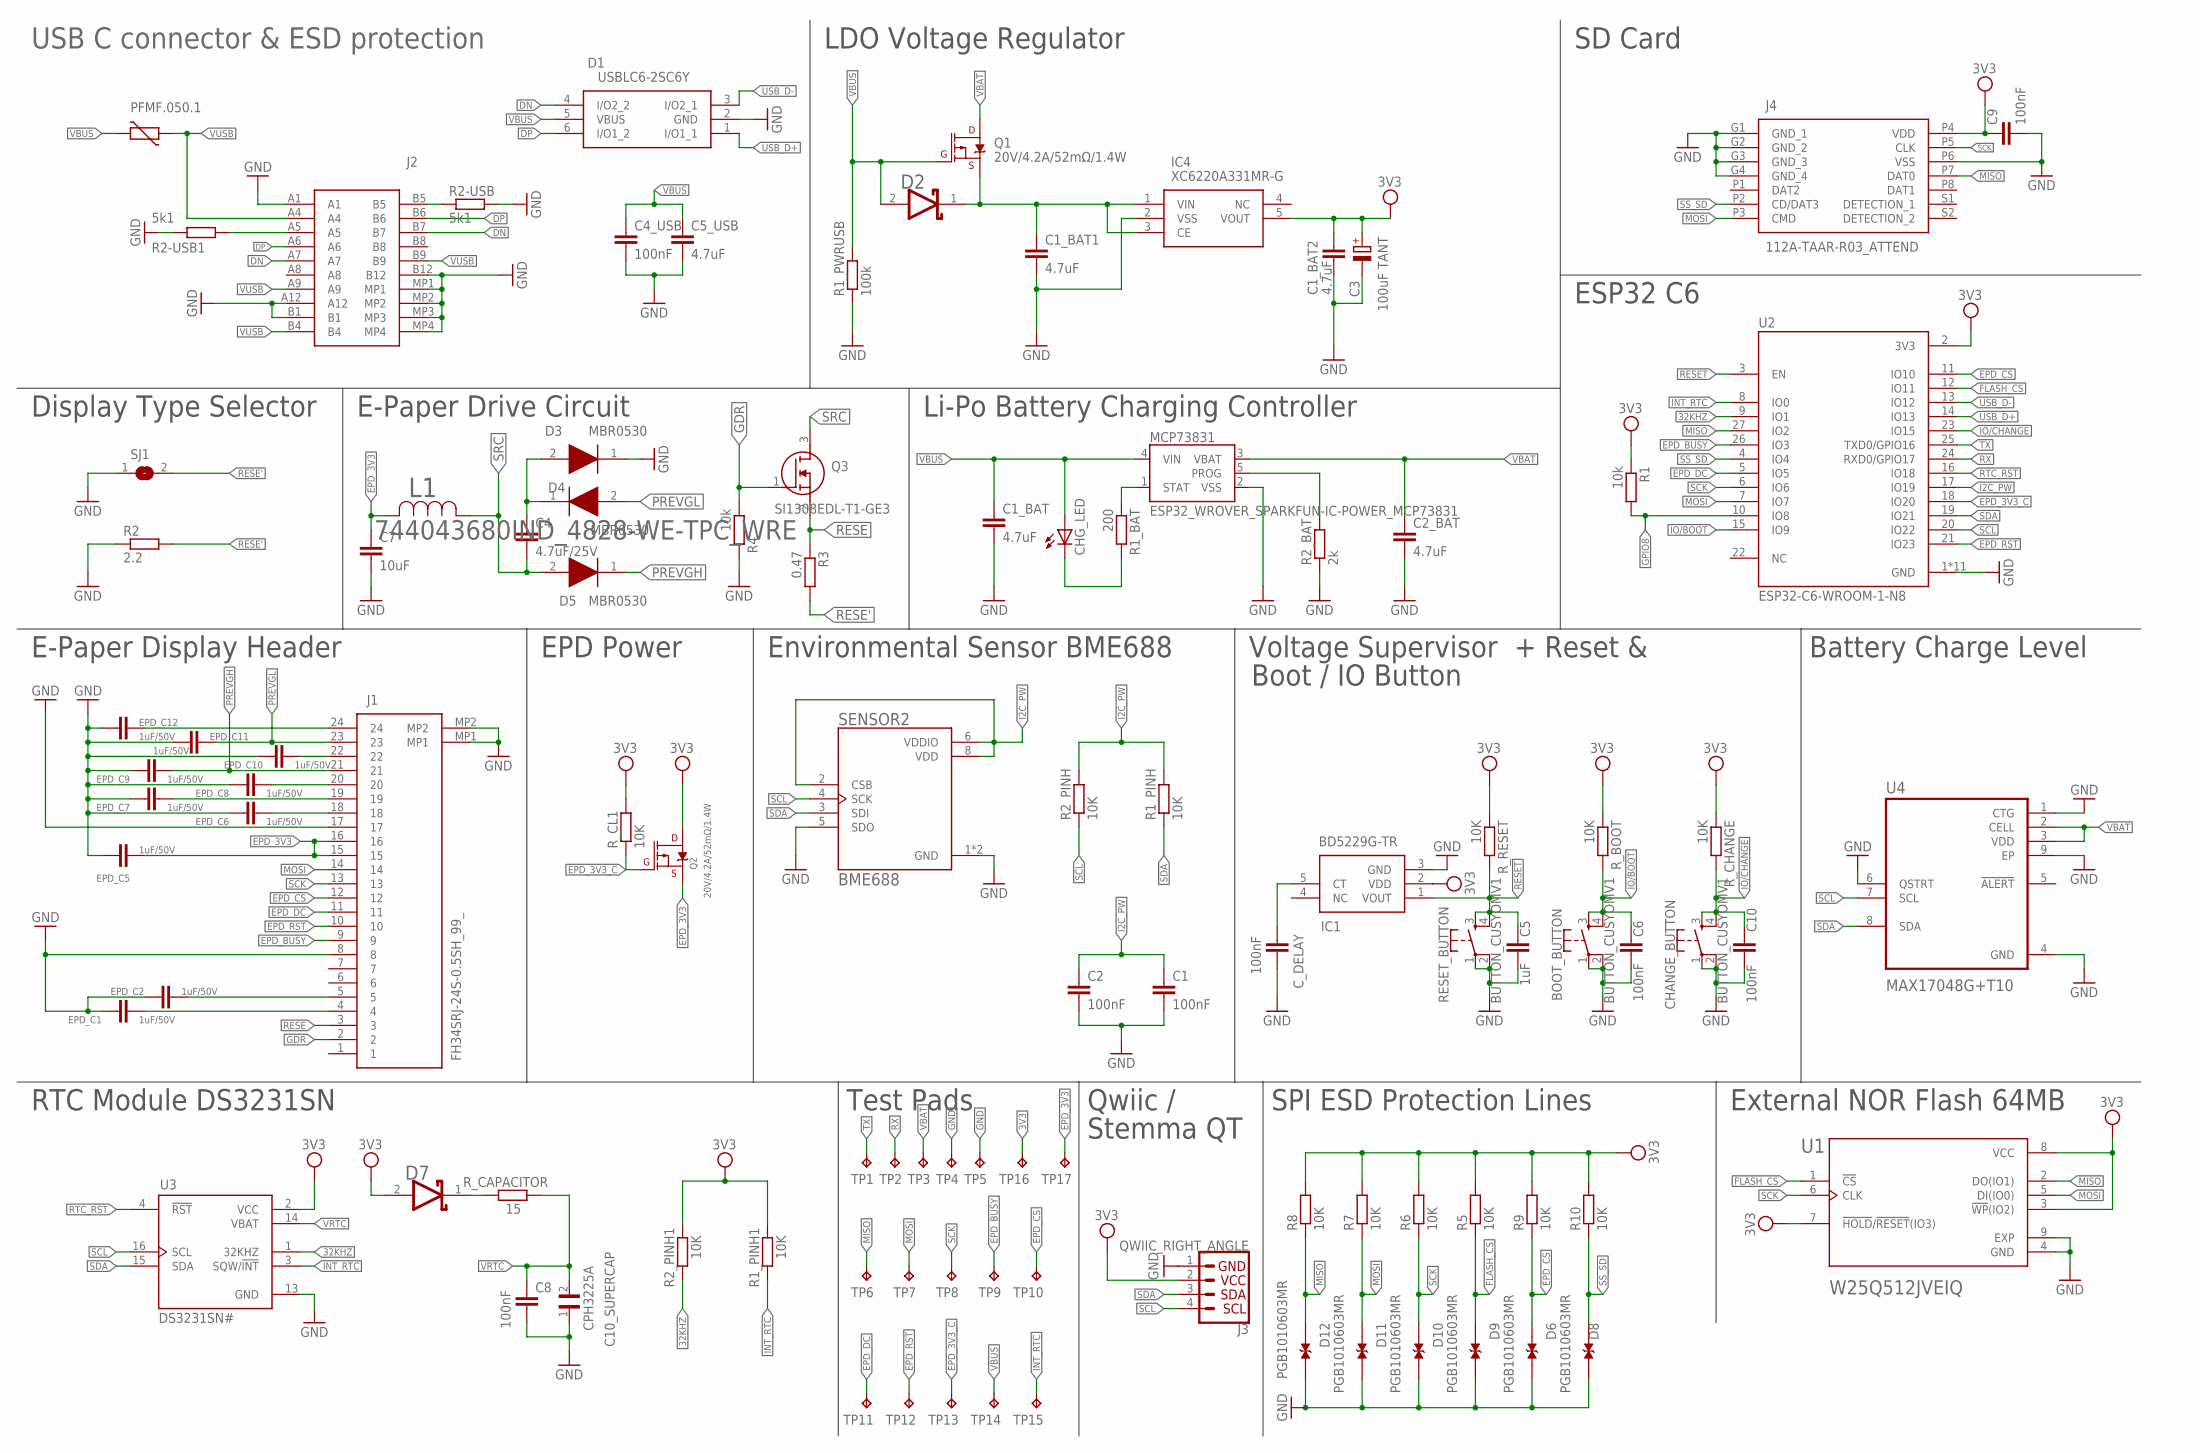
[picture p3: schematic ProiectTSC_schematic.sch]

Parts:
BOOT_BUTTON: BUTTON_CUSYOMV1; MYBUTTON
C1, C2, C4_USB, C6, C8, C9, C10: 100nF; ESP32_WROVER_EAGLE-LTSPICE_C0402
C1_BAT, C1_BAT1, C1_BAT2, C2_BAT, C5_USB: 4.7uF; ESP32_WROVER_EAGLE-LTSPICE_C0402
C3: 100uF TANT; RCL_CT3528
C4: 4.7uF/25V; ESP32_WROVER_EAGLE-LTSPICE_C0402
C5: 1uF; ESP32_WROVER_EAGLE-LTSPICE_C0402
C7: 10uF; ESP32_WROVER_EAGLE-LTSPICE_C0402
C10_SUPERCAP: CPH3225A; CAPCP3225X100N
CHANGE_BUTTON: BUTTON_CUSYOMV1; MYBUTTON
CHG_LED: ADAFRUIT_LEDCHIP-LED0603; ADAFRUIT_CHIP-LED0603
C_DELAY: 100nF; ESP32_WROVER_EAGLE-LTSPICE_C0402
D1: USBLC6-2SC6Y; SOT95P280X145-6N
D2, D7: SD0805S020S1R0; ESP32_WROVER_AVX---SD0805S020S1R0_AVX_SD0805S020S1R0_0
D3, D4, D5: MBR0530; SOD3716X135N
D6, D8, D9, D10, D11, D12: PGB1010603MR; DIOC1608X36N
EPD_C1, EPD_C2, EPD_C5, EPD_C6, EPD_C7, EPD_C8, EPD_C9, EPD_C10, EPD_C11, EPD_C12: 1uF/50V; ESP32_WROVER_EAGLE-LTSPICE_C0402
IC1: BD5229G-TR; SOT95P280X120-5N
IC4: XC6220A331MR-G; SOT95P280X120-5N
J1: FH34SRJ-24S-0.5SH_99_; FH34SRJ24S05SH99
J2: SAMACSYS_PARTS_USB4110-GF-A; SAMACSYS_PARTS_USB4110GFA
J3: QWIIC_RIGHT_ANGLE; JST04_1MM_RA
J4: 112A-TAAR-R03_ATTEND; 112ATAARR03ATTEND
L1: 744043680IND_4828-WE-TPC_WRE; IND_4828-WE-TPC_WRE
MCP73831: ESP32_WROVER_SPARKFUN-IC-POWER_MCP73831; ESP32_WROVER_SPARKFUN-IC-POWER_SOT23-5
PFMF.050.1: ESP32C6_VARISTORCN1812; ESP32C6_VARISTOR_CT/CN1812
Q1, Q2: 20V/4.2A/52mΩ/1.4W; ESP32_WROVER_SPARKFUN-DISCRETESEMI_SOT23-3
Q3: SI1308EDL-T1-GE3; SOT65P210X110-3N
R1, R4: 10k; ESP32_WROVER_EAGLE-LTSPICE_R0402
R1_BAT: 200; ESP32_WROVER_EAGLE-LTSPICE_R0402
R1_PINH, R1_PINH1, R2_PINH, R2_PINH1, R5, R6, R7, R8, R9, R10: 10K; ESP32_WROVER_EAGLE-LTSPICE_R0402
R1_PWRUSB: 100k; ESP32_WROVER_EAGLE-LTSPICE_R0402
R2: 2.2; ESP32_WROVER_EAGLE-LTSPICE_R0402
R2-USB, R2-USB1: 5k1; ESP32_WROVER_EAGLE-LTSPICE_R0402
R2_BAT: 2k; ESP32_WROVER_EAGLE-LTSPICE_R0402
R3: 0.47; ESP32_WROVER_EAGLE-LTSPICE_R0402
RESET_BUTTON: BUTTON_CUSYOMV1; MYBUTTON
R_BOOT: 10K; ESP32_WROVER_EAGLE-LTSPICE_R0402
R_CAPACITOR: 15; ESP32_WROVER_EAGLE-LTSPICE_R0402
R_CHANGE: 10K; ESP32_WROVER_EAGLE-LTSPICE_R0402
R_CL1: 10K; ESP32_WROVER_EAGLE-LTSPICE_R0402
R_RESET: 10K; ESP32_WROVER_EAGLE-LTSPICE_R0402
SENSOR2: BME688; ESP32_WROVER_BME680_PSON80P300X300X100-8N
SJ1: SJ
TP1, TP2, TP3, TP4, TP5, TP6, TP7, TP8, TP9, TP10, TP11, TP12, TP13, TP14, TP15, TP16, TP17: TPTP20R; TP20R
U1: W25Q512JVEIQ; SON127P600X800X80-9N
U2: ESP32-C6-WROOM-1-N8; XCVR_ESP32-C6-WROOM-1-N8
U3: DS3231SN#; SOIC127P1032X265-16N
U4: MAX17048G+T10; SON50P200X200X80-9N

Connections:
3V3: C1_BAT2.1, C3.+, C9.1, D7.2 (ANODE), IC1.2 (VDD), IC4.5 (VOUT), J3.2, J4.P4 (VDD), Q2.3 (D), R1.1, R1_PINH1.2, R2_PINH1.2, R5.2, R6.2, R7.2, R8.2, R9.2, R10.2, R_BOOT.1, R_CHANGE.1, R_CL1.2, R_RESET.1, TP16.TP, U1.3 (!WP!(IO2)), U1.7 (!HOLD!/!RESET!(IO3)), U1.8 (VCC), U2.2 (3V3), U3.2 (VCC)
32KHZ: R2_PINH1.1, U2.9 (IO1), U3.1 (32KHZ)
DN: D1.4 (I/O2_2), J2.A7, J2.B7
DP: D1.6 (I/O1_2), J2.A6, J2.B6
EPD_3V3: C7.1, EPD_C5.1, J1.15, J1.16, L1.2, Q2.2 (S), TP17.TP
EPD_3V3_C: Q2.1 (G), R_CL1.1, TP13.TP, U2.18 (IO20)
EPD_BUSY: J1.9, TP9.TP, U2.26 (IO3)
EPD_CS: D6.1, J1.12, R9.1, TP10.TP, U2.11 (IO10)
EPD_DC: J1.11, TP11.TP, U2.5 (IO5)
EPD_RST: J1.10, TP12.TP, U2.21 (IO23)
FLASH_CS: D9.1, R5.1, U1.1 (!CS), U2.12 (IO11)
GDR: J1.2, Q3.1 (G), R4.1
GND: BOOT_BUTTON.1, BOOT_BUTTON.2, C1.2, C1_BAT.2, C1_BAT1.2, C1_BAT2.2, C2.2, C2_BAT.2, C3.-, C4_USB.2, C5.2, C5_USB.2, C6.2, C7.2, C8.2, C9.2, C10.2, C10_SUPERCAP.1, CHANGE_BUTTON.1, CHANGE_BUTTON.2, C_DELAY.2, D1.2 (GND), D3.1 (K), D6.2, D8.2, D9.2, D10.2, D11.2, D12.2, EPD_C1.2, EPD_C2.2, EPD_C5.2, EPD_C6.2, EPD_C7.2, EPD_C8.2, EPD_C9.2, EPD_C10.2, EPD_C11.2, EPD_C12.2, IC1.3 (GND), IC4.2 (VSS), J1.8, J1.17, J1.MP1, J1.MP2, J2.A1, J2.A12, J2.B1, J2.B12, J2.MP1, J2.MP2, J2.MP3, J2.MP4, J3.1, J4.G1 (GND_1), J4.G2 (GND_2), J4.G3 (GND_3), J4.G4 (GND_4), J4.P6 (VSS), MCP73831.2 (VSS), R1_PWRUSB.1, R2.1, R2-USB.2, R2-USB1.1, R2_BAT.1, R4.2, RESET_BUTTON.1, RESET_BUTTON.2, SENSOR2.1 (GND), SENSOR2.5 (SDO), SENSOR2.7 (GND), SJ1.1, TP4.TP, TP5.TP, U1.4 (GND), U1.9 (EXP), U2.1 (GND), U2.28 (GND), U2.29_1 (GND), U2.29_2 (GND), U2.29_3 (GND), U2.29_4 (GND), U2.29_5 (GND), U2.29_6 (GND), U2.29_7 (GND), U2.29_8 (GND), U2.29_9 (GND), U3.13 (GND), U4.1 (CTG), U4.4 (GND), U4.6 (QSTRT), U4.9 (EP)
GPIO8: R1.2, U2.10 (IO8)
I2C_PW: C1.1, C2.1, R1_PINH.2, R2_PINH.2, SENSOR2.2 (CSB), SENSOR2.6 (VDDIO), SENSOR2.8 (VDD), U2.17 (IO19)
INT_RTC: R1_PINH1.1, TP15.TP, U2.8 (IO0), U3.3 (SQW/!INT)
IO/BOOT: BOOT_BUTTON.3, BOOT_BUTTON.4, C6.1, R_BOOT.2, U2.15 (IO9)
IO/CHANGE: C10.1, CHANGE_BUTTON.3, CHANGE_BUTTON.4, R_CHANGE.2, U2.23 (IO15)
MISO: D12.1, J4.P7 (DAT0), R8.1, TP6.TP, U1.2 (DO(IO1)), U2.27 (IO2)
MOSI: D11.1, J1.14, J4.P3 (CMD), R7.1, TP7.TP, U1.5 (DI(IO0)), U2.7 (IO7)
unnamed: J2.A5, R2-USB1.2
unnamed: C4.1, D3.2 (A), D4.1 (K)
unnamed: MCP73831.1 (STAT), R1_BAT.1
unnamed: CHG_LED.C, R1_BAT.2
unnamed: J2.B5, R2-USB.1
unnamed: MCP73831.5 (PROG), R2_BAT.2
unnamed: EPD_C10.1, J1.22
unnamed: EPD_C12.1, J1.24
unnamed: C1_BAT1.1, D2.1 (CATHODE), IC4.1 (VIN), IC4.3 (CE), Q1.2 (S)
unnamed: EPD_C8.1, J1.20
unnamed: EPD_C7.1, J1.19
unnamed: EPD_C6.1, J1.18
unnamed: EPD_C2.1, J1.5
unnamed: EPD_C1.1, J1.4
unnamed: C_DELAY.1, IC1.5 (CT)
unnamed: D7.1 (CATHODE), R_CAPACITOR.1
PREVGH: D5.1 (K), EPD_C9.1, J1.21
PREVGL: D4.2 (A), EPD_C11.1, J1.23
RESE: J1.3, Q3.2 (S), R3.1
RESE': R2.2, R3.2, SJ1.2
RESET: C5.1, IC1.1 (VOUT), RESET_BUTTON.3, RESET_BUTTON.4, R_RESET.2, U2.3 (EN)
RTC_RST: U2.16 (IO18), U3.4 (!RST)
RX: TP2.TP, U2.24 (RXD0/GPIO17)
SCK: D10.1, J1.13, J4.P5 (CLK), R6.1, TP8.TP, U1.6 (CLK), U2.6 (IO6)
SCL: J3.4, R2_PINH.1, SENSOR2.4 (SCK), U2.20 (IO22), U3.16 (SCL), U4.7 (SCL)
SDA: J3.3, R1_PINH.1, SENSOR2.3 (SDI), U2.19 (IO21), U3.15 (SDA), U4.8 (SDA)
SRC: C4.2, D5.2 (A), L1.1, Q3.3 (D)
SS_SD: D8.1, J4.P2 (CD/DAT3), R10.1, U2.4 (IO4)
TX: TP1.TP, U2.25 (TXD0/GPIO16)
USB_D+: D1.1 (I/O1_1), U2.14 (IO13)
USB_D-: D1.3 (I/O2_1), U2.13 (IO12)
VBAT: C2_BAT.1, MCP73831.3 (VBAT), Q1.3 (D), TP3.TP, U4.2 (CELL), U4.3 (VDD)
VBUS: C1_BAT.1, C4_USB.1, C5_USB.1, CHG_LED.A, D1.5 (VBUS), D2.2 (ANODE), MCP73831.4 (VIN), PFMF.050.1.2, Q1.1 (G), R1_PWRUSB.2, TP14.TP
VRTC: C8.1, C10_SUPERCAP.2, R_CAPACITOR.2, U3.14 (VBAT)
VUSB: J2.A4, J2.A9, J2.B4, J2.B9, PFMF.050.1.1

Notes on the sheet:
USB C connector & ESD protection
LDO Voltage Regulator
SD Card
ESP32 C6
Display Type Selector
E-Paper Drive Circuit
Li-Po Battery Charging Controller
E-Paper Display Header
EPD Power
Environmental Sensor BME688
Voltage Supervisor + Reset &
Boot / IO Button
Battery Charge Level
RTC Module DS3231SN
Test Pads
Qwiic /
Stemma QT
SPI ESD Protection Lines
External NOR Flash 64MB

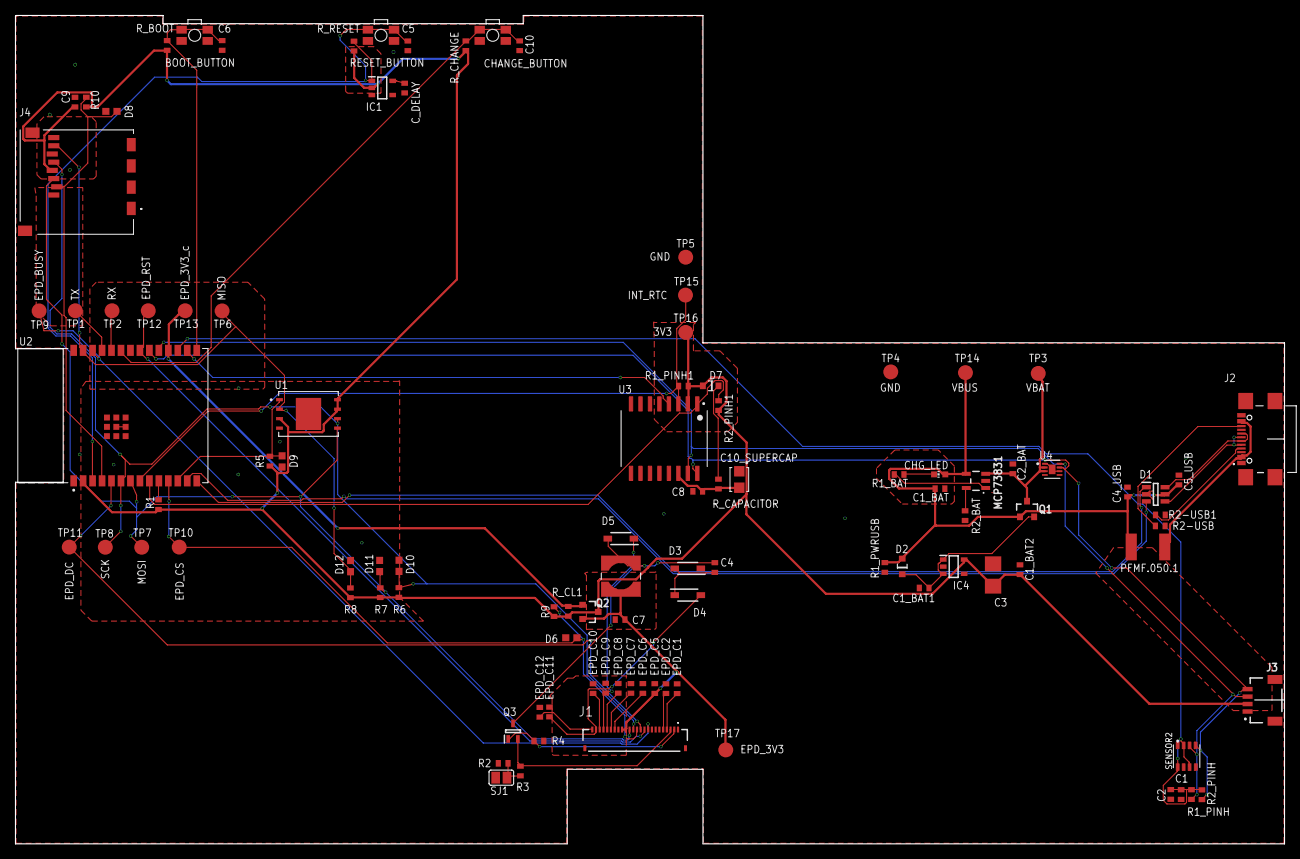
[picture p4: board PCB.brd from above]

Board: 2 copper layers, 170.2 x 111.1 mm, 103 parts (0 on the bottom side), 55 nets.

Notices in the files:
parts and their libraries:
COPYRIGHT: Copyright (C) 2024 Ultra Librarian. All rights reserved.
